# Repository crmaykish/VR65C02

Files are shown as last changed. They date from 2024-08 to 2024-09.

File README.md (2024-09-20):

# VR65C02
A 6502 computer system with an ATmega4809 simulating all of the memory and I/O. Two ICs are enough to run native 6502 code on the real silicon. All of the 6502's interactions with the outside world go through the microcontroller.

It's like the 6502 is wearing the ATmega as a VR headset! (AVR headset?)

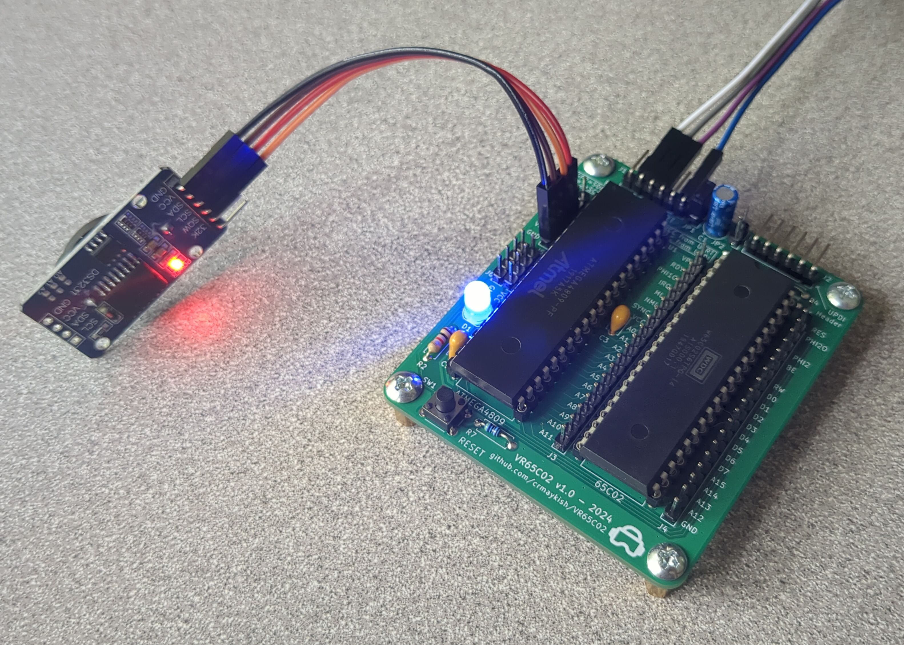
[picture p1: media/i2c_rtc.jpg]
Prototype


## Background

### TL;DR

- Real 6502 code running on a real 6502
- ATmega4809 microcontroller emulates everything else
- 6502 is programmed by uploading an Arduino sketch
- 5KB of emulated RAM, up to 32KB emulated ROM
- Memory-mapped UART, GPIO, and I2C peripherals for the 6502
- Eye-watering clock speed of ~250 kHz!

### Why?

Why not? This project started as a weekend experiment to see if I could run a 6502 CPU without having to use a real ROM chip. That quickly turned into "Can I run 6502 code on a real CPU without any real memory or peripherals attached. The answer is yes.

This computer is not fast. It's not practical, but it is kind of fun.

### Why not a Raspberry Pi Pico or FPGA?

Those would both likely be better choices, but to be totally honest, the availability of the ATmega4809 in a 40 pin DIP package is what sold me. I like the aesthetic of two DIP ICs. That's really it.

## Features

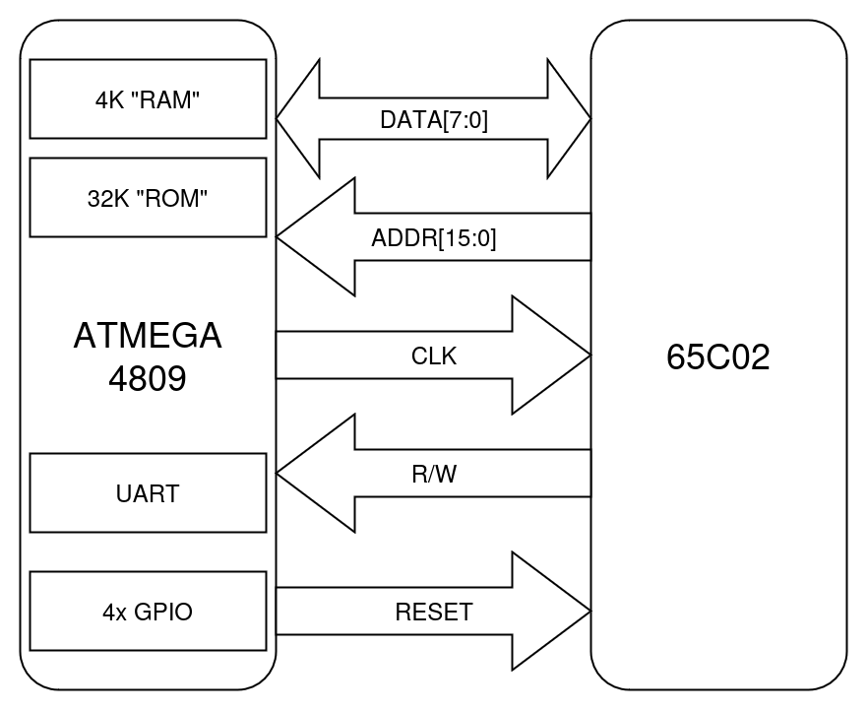
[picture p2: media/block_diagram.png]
VR65C02 Block Diagram


### Memory Emulation

VR65C02 is a fully functional computer system. The ATmega microcontroller provides emulated RAM and ROM as well as a passthrough UART and four GPIO pins that the 6502 can access.

The microcontroller controls the RESET and CLOCK lines of the CPU, so all memory access is handled synchronously by the Arduino code. For each bus cycle, the microcontroller reads the address bus and R/W pin from the CPU. If the CPU is reading a memory address, the microcontroller will decode the address into a memory value or an I/O operation and write the appropriate value out to the data bus. On a write cycle, the microcontroller reads the data bus value into its simulated RAM or updates the appropriate I/O system. The microcontroller implements address decoding in code in a similar way to a traditional system using logic gates or PLDs.

Both RAM and ROM are backed by large byte arrays in the microcontroller's memory, the RAM using onboard SRAM and the ROM using onboard Flash.

### I/O Emulation

The UART is a memory-mapped I/O device from the perspective of the 6502, similar to a 6551 ACIA. The CPU can read and write bytes and the microcontroller passes them through to one of its native serial ports.

Similarly, there are four GPIO pins accessible as a memory-mapped register to the 6502.

These GPIO ports have two alternate functions. If SOFT_RESET is defined in [memory_map.h](src/6502_vr_goggles/memory_map.h), then GPIO pin 0 will function as a reset pin for the 6502. It does not reset the Arduino, but it triggers the Arduino to reset the 6502. If soft reset is enabled, pin 0 cannot be used as a normal GPIO pin.

I2C devices can also be attached to the GPIO pins. GPIO 2 and 3 double as SDA and SCL respectively. The Arduino provides low level access to the I2C bus through a few memory-mapped registers. The 6502 can enable/disable the I2C bus, set the active peripheral address, and read/write data through these registers.

See [memory_map.h](src/6502_vr_goggles/memory_map.h) for more details.

It should also be possible to implement SPI passthrough in a similar fashion, but I2C is really a better fit for this system, especially considering its slow clock speed and lack of I/O lines. With I2C, a ton of peripherals can be daisy-chained and there is still room for 1 or 2 GPIO pins. I've tested reading a real-time clock module over I2C from the 6502 code (see the `time` command in [monitor.c](src/monitor.c)).

### Memory Map

The memory map of the 6502 is as follows:
1. 5KB "RAM" at 0x0000
2. I/O regisers at 0x7F00
3. 8KB "ROM" at 0xE000

The ATmega4809 has enough flash memory to support up to 32KB of ROM if necessary, but the total onboard SRAM is only 6KB and some is set aside for the Arduino code.

## Software

The core of VR65C02 is the Arduino sketch running on the ATmega4809. As described above, this program simulates the entire bus cycle of the physical 6502 CPU and all of the memory and I/O interactions.

Real 6502 machine code is running on the CPU. This can be assembly or C code compiled with cc65. Since there is no physical ROM or RAM, the code has to live somewhere. My approach is to use the large amount of onboard Flash memory of the ATmega to store this. The main trick of VR65C02 is taking this compiled binary and getting it into the microcontroller Flash as part of the Arduino sketch upload.

### Setup

To build and deploy code to the VR65C02, you'll need to setup the following:
1. Install Arduino to `/opt/local`
2. Install MegaCoreX Arduino package
3. Install cc65 or some other 6502 compiler/assembler
4. Install make (`build-essential` on Debian/Ubuntu)
5. Install Python 3.x

Note: you may need to update the build.sh script if you're on a different platform. Windows will probably require a different approach.

### Building

The build process is done in a single script, [build.sh](src/build.sh). The process looks like this:
1. Compile 6502 C code into a binary ROM file.
2. Run a Python script to convert this binary file into a C header file with a large const array of bytes.
3. Compile the Arduino sketch with this generated header file.
4. Upload Arduino sketch to microcontroller with new 6502 code.

### Programming the ATmega (and by extension the 6502)

Programming the ATmega4809 is done via UPDI. UPDI is a one-wire programming interface that can be implemented over a simple serial port. On VR65C02, the wiring is already done on the board, so a standard FTDI-style USB-UART can be plugged into the onboard UPDI header. In the Arduino IDE, the SerialUPDI programmer included in MegaCoreX at 230400 baud will work just fine. Make sure to set the serial port to the UPDI USB device and not the one plugged into the UART port.

Note: the board and programmer selection is already done in the [build.sh](src/build.sh) script using the `arduino-cli` command.

It's possible to use a single FTDI device and switch between the headers on board for programming versus serial monitoring, but having two different serial ports is a lot more convenient.

## Limitations

All of the limitations of this system come down to hitting the limits of the ATmega4809 itself in one way or another.

### Clock Speed

The main drawback is obviously clock speed. Simulating the whole bus cycle and all of the potential memory and I/O operations of the 6502 on a 20 MHz 8-bit microcontroller is not exactly quick. Measuring the PHI2 output on the CPU with an oscilloscope shows that the effective clock speed is about 257 kHz. Even at this speed, VR65C02 is surprisingly usable for simple GPIO tasks or interacting over the serial port, but it's about 4x slower than a Commodore 64 or Apple II.

Because not all the emulated peripherals respond at the same speed, the effective clock speed is actually somewhat variable depending on the I/O demands of the 6502 code. This doesn't fluctuate too dramatically, but heavy I/O, e.g. polling the serial port, will run at around 257 kHz, whereas no I/O at all will get the clock up to about 270 kHz.

### Not Enough Pins

Besides the slow speed, the other main limitations is the lack of available pins on the ATmega. All 31 available IO pins are being used to connect to the 6502 bus and control signals. Two of the pins are used for the serial port and four are set up as GPIO. The GPIO pins could be used for other things, but there's not a huge number to spare.

In theory, these GPIO pins could be repurposed as chip-select signals to attach some real I/O devices to the system. It wouldn't be a stretch to attach a real RAM chip and have the microcontroller copy the program code from Flash into that RAM. In that scenario, a real clock oscillator could be used and the Arduino would become a slow peripheral using the RDY pin to handle the higher clock rate.

The ATmega4809 is also available in a 48 pin QFP package with quite a few more I/O pins. This might be fun to explore, but it would definitely detract from the DIP aesthetic and make VR65C02 harder to build.

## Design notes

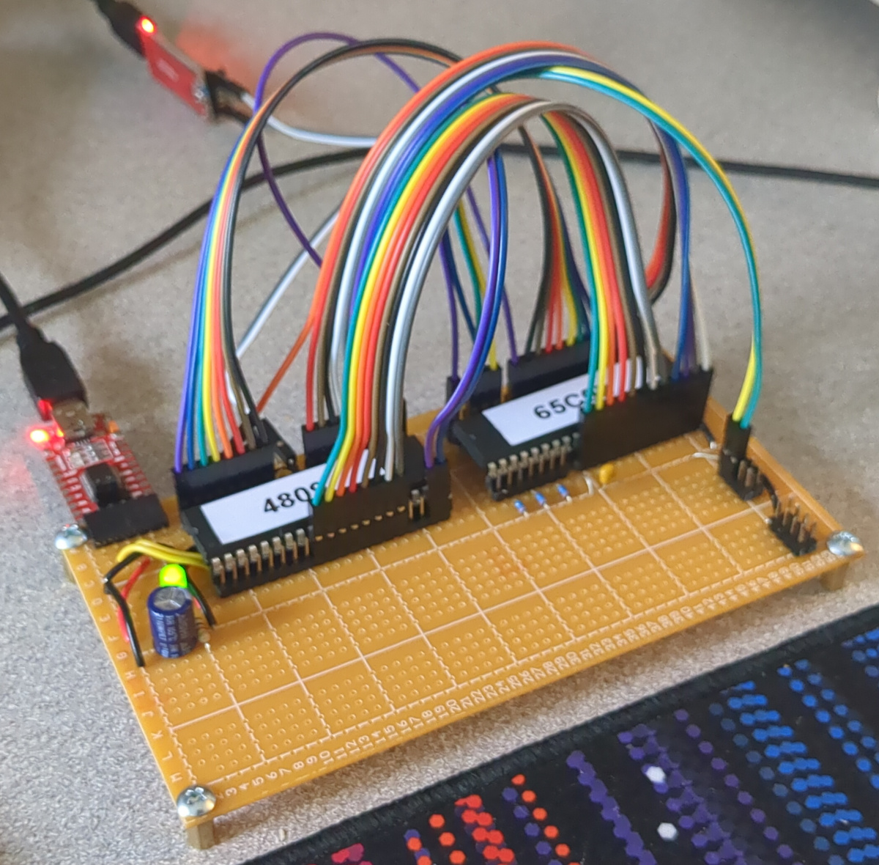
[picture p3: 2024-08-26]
media/prototype.jpg

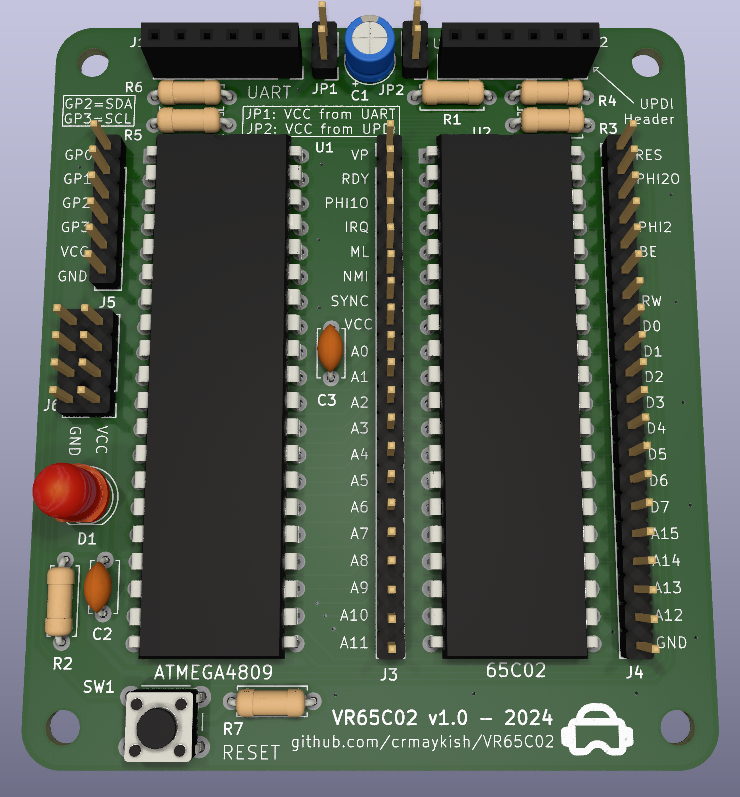
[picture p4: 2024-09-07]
media/render1.png

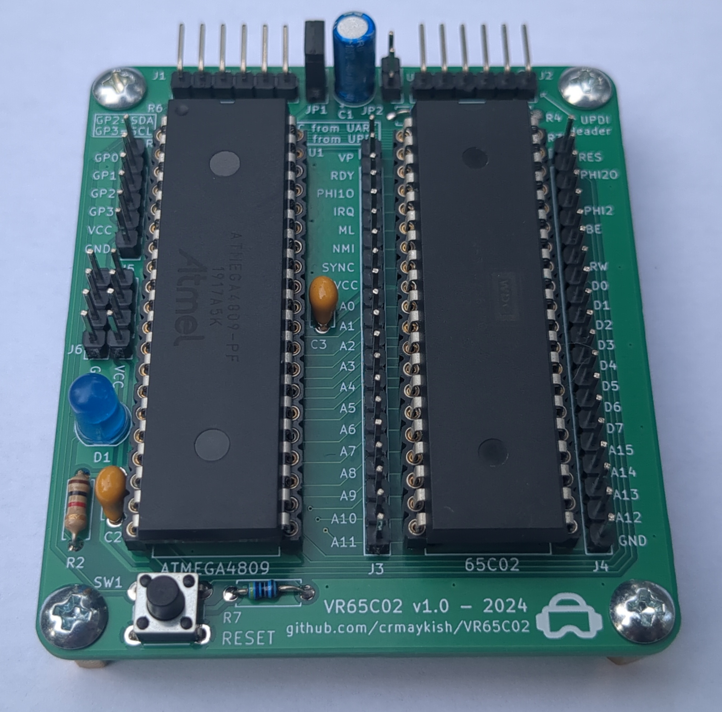
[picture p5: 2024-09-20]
media/pcb_v1.jpg

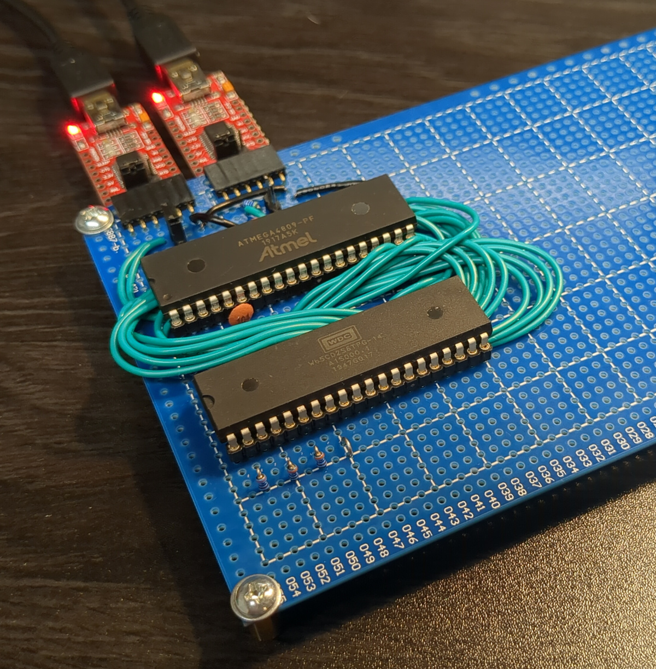
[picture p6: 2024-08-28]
media/prototype2.jpg

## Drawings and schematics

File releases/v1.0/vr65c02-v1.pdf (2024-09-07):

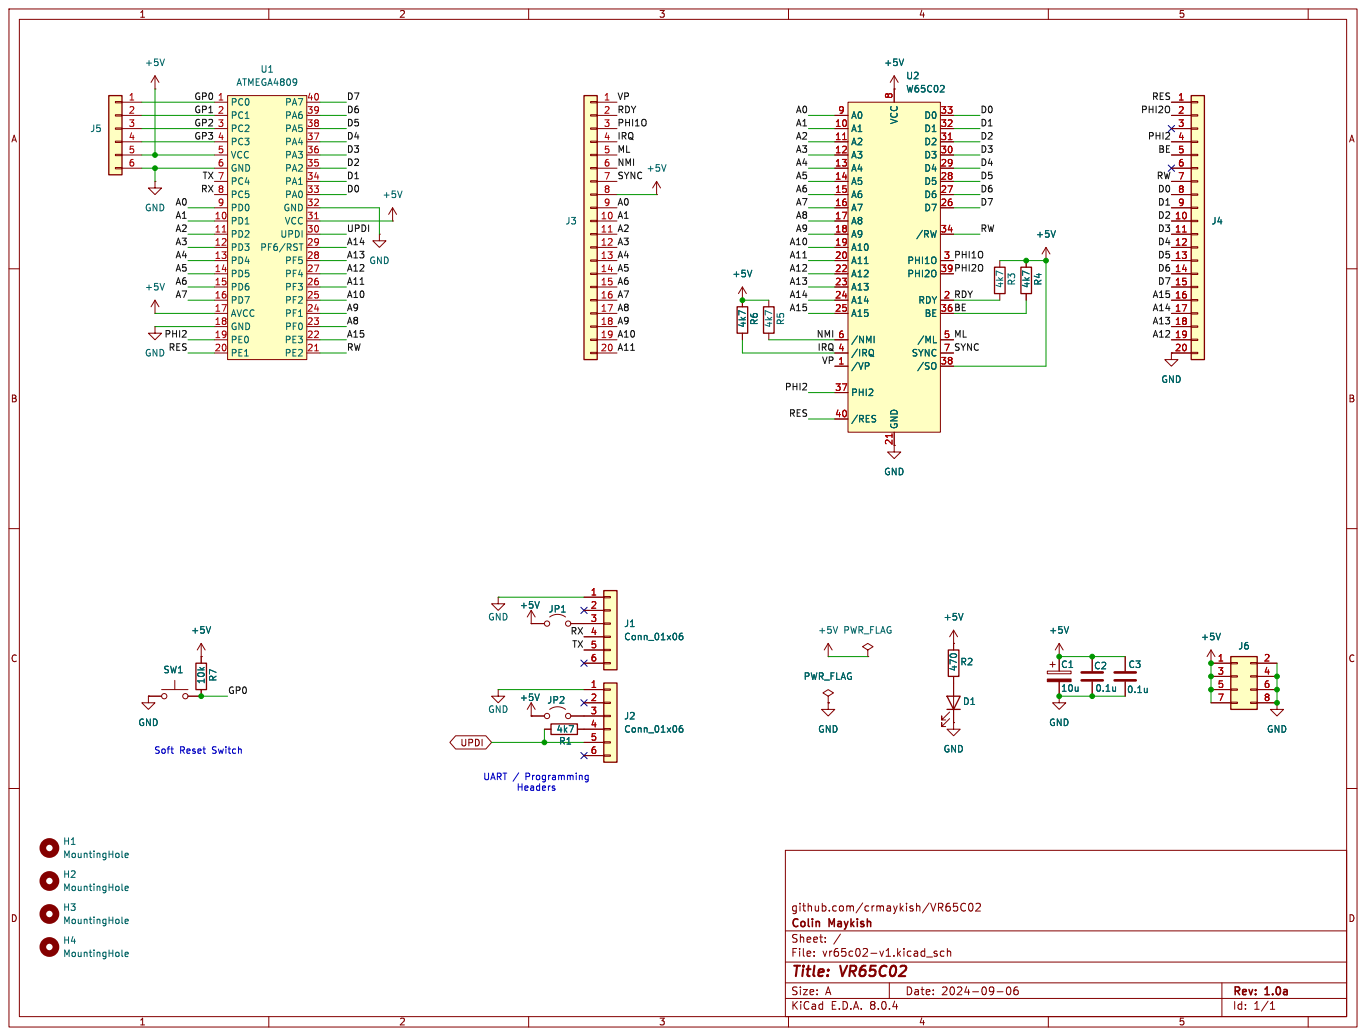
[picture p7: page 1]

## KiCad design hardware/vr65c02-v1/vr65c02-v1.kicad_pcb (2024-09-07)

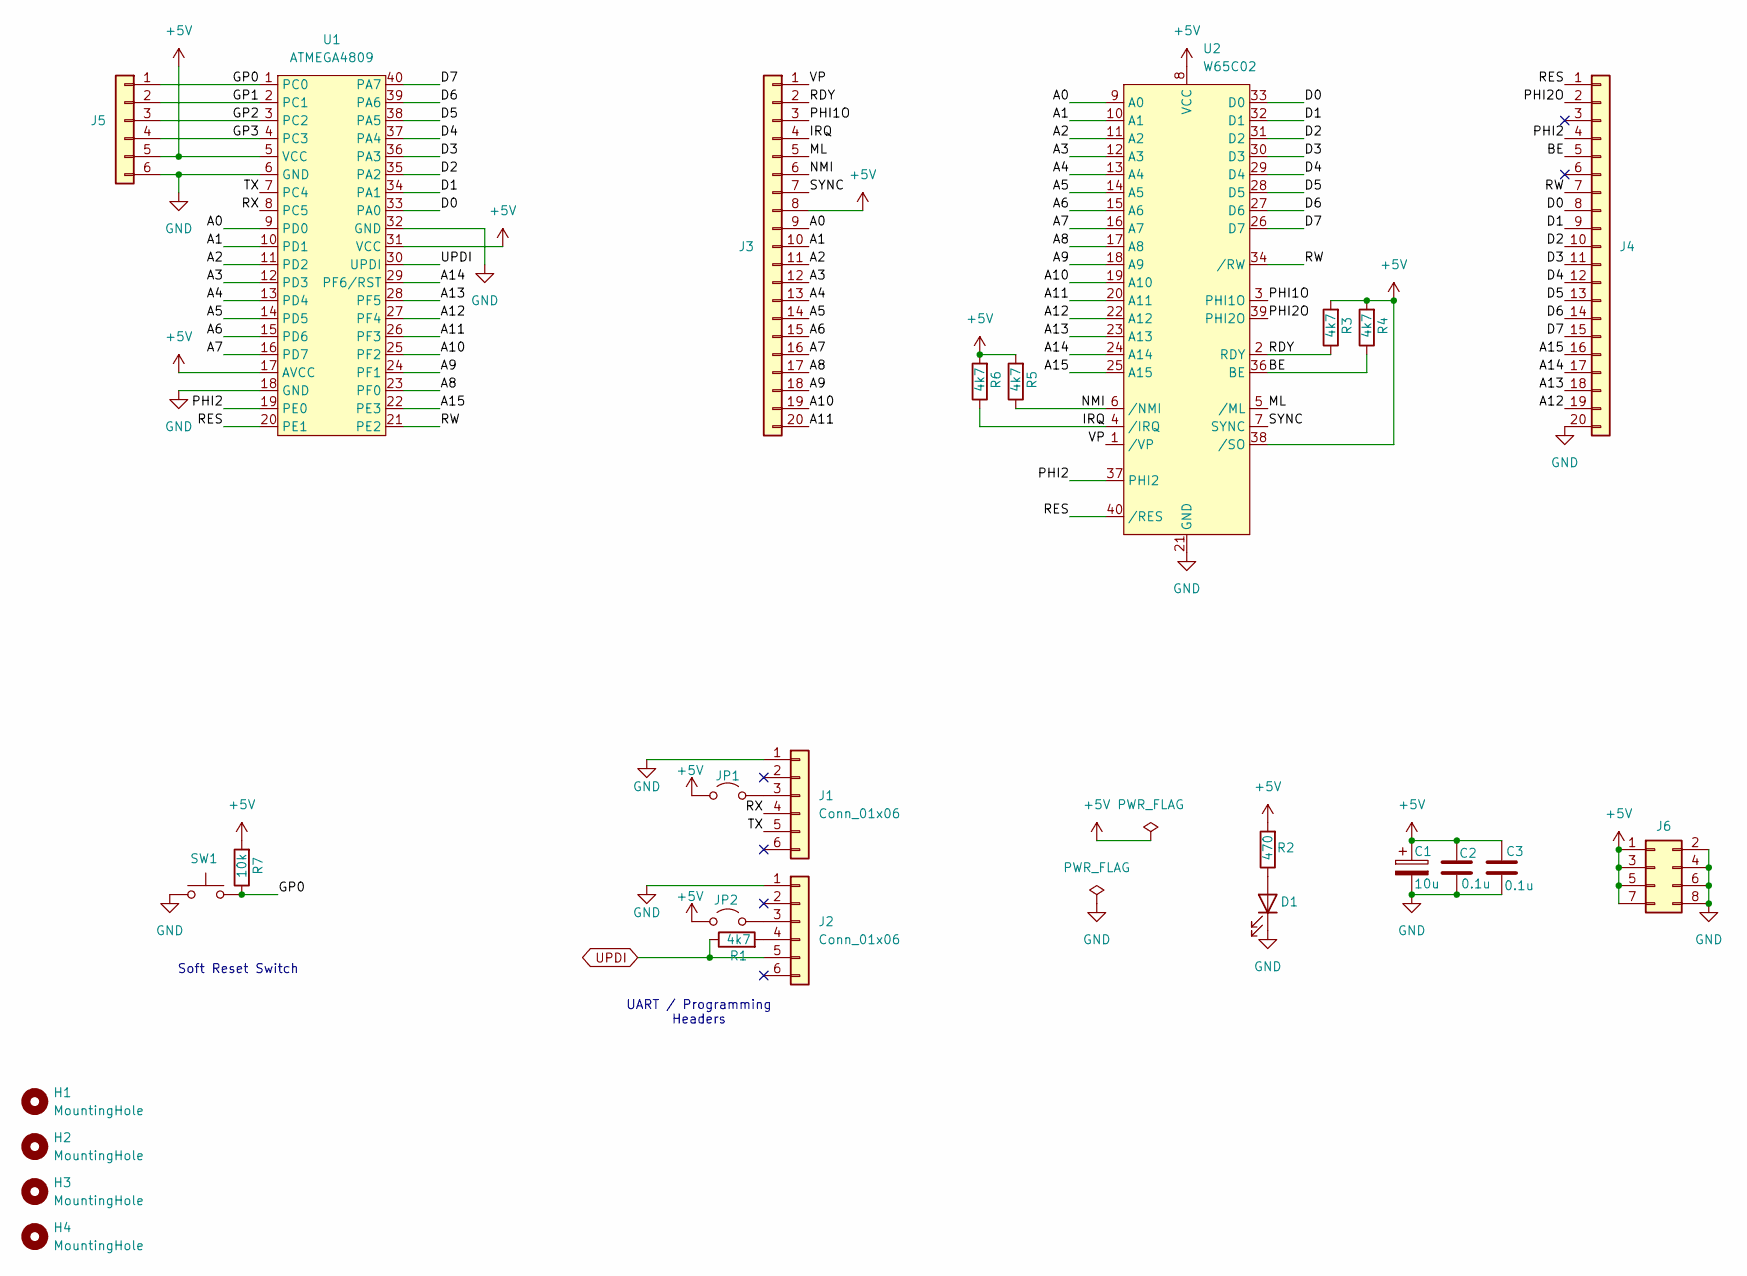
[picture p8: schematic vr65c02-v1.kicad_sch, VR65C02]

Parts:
C1: 10u; CP_Radial_D5.0mm_P2.50mm
C2, C3: 0.1u; C_Disc_D4.7mm_W2.5mm_P5.00mm
D1: LED; LED_D5.0mm
H1, H2, H3, H4: MountingHole; MountingHole_3.2mm_M3
J1, J2: Conn_01x06; PinSocket_1x06_P2.54mm_Vertical
J3, J4: Conn_01x20; PinHeader_1x20_P2.54mm_Vertical
J5: Conn_01x06; PinHeader_1x06_P2.54mm_Vertical
J6: Conn_02x04_Odd_Even; PinHeader_2x04_P2.54mm_Vertical
JP1, JP2: Jumper_2_Open; PinHeader_1x02_P2.54mm_Vertical
R1, R3, R4, R5, R6: 4k7; R_Axial_DIN0207_L6.3mm_D2.5mm_P7.62mm_Horizontal
R2: 470; R_Axial_DIN0207_L6.3mm_D2.5mm_P7.62mm_Horizontal
R7: 10k; R_Axial_DIN0207_L6.3mm_D2.5mm_P7.62mm_Horizontal
SW1: SW_Push; SW_PUSH_6mm_H5mm
U1: ATMEGA4809; DIP-40_W15.24mm
U2: W65C02; DIP-40_W15.24mm

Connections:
+5V: C1.1, C2.1, C3.1, J3.8, J5.5, J6.1, J6.3, J6.5, J6.7, JP1.1 (A), JP2.1 (A), R2.2, R3.2, R4.2, R5.2, R6.2, R7.2, U1.5 (VCC), U1.17 (AVCC), U1.31 (VCC), U2.8 (VCC), U2.38 (/SO)
/A0: J3.9, U1.9 (PD0), U2.9 (A0)
/A1: J3.10, U1.10 (PD1), U2.10 (A1)
/A2: J3.11, U1.11 (PD2), U2.11 (A2)
/A3: J3.12, U1.12 (PD3), U2.12 (A3)
/A4: J3.13, U1.13 (PD4), U2.13 (A4)
/A5: J3.14, U1.14 (PD5), U2.14 (A5)
/A6: J3.15, U1.15 (PD6), U2.15 (A6)
/A7: J3.16, U1.16 (PD7), U2.16 (A7)
/A8: J3.17, U1.23 (PF0), U2.17 (A8)
/A9: J3.18, U1.24 (PF1), U2.18 (A9)
/A10: J3.19, U1.25 (PF2), U2.19 (A10)
/A11: J3.20, U1.26 (PF3), U2.20 (A11)
/A12: J4.19, U1.27 (PF4), U2.22 (A12)
/A13: J4.18, U1.28 (PF5), U2.23 (A13)
/A14: J4.17, U1.29 (PF6/RST), U2.24 (A14)
/A15: J4.16, U1.22 (PE3), U2.25 (A15)
/BE: J4.5, R4.1, U2.36 (BE)
/D0: J4.8, U1.33 (PA0), U2.33 (D0)
/D1: J4.9, U1.34 (PA1), U2.32 (D1)
/D2: J4.10, U1.35 (PA2), U2.31 (D2)
/D3: J4.11, U1.36 (PA3), U2.30 (D3)
/D4: J4.12, U1.37 (PA4), U2.29 (D4)
/D5: J4.13, U1.38 (PA5), U2.28 (D5)
/D6: J4.14, U1.39 (PA6), U2.27 (D6)
/D7: J4.15, U1.40 (PA7), U2.26 (D7)
/GP0: J5.1, R7.1, SW1.2, U1.1 (PC0)
/GP1: J5.2, U1.2 (PC1)
/GP2: J5.3, U1.3 (PC2)
/GP3: J5.4, U1.4 (PC3)
/IRQ: J3.4, R6.1, U2.4 (/IRQ)
/ML: J3.5, U2.5 (/ML)
/NMI: J3.6, R5.1, U2.6 (/NMI)
/PHI1O: J3.3, U2.3 (PHI1O)
/PHI2: J4.4, U1.19 (PE0), U2.37 (PHI2)
/PHI2O: J4.2, U2.39 (PHI2O)
/RDY: J3.2, R3.1, U2.2 (RDY)
/RES: J4.1, U1.20 (PE1), U2.40 (/RES)
/RW: J4.7, U1.21 (PE2), U2.34 (/RW)
/RX: J1.4, U1.8 (PC5)
/SYNC: J3.7, U2.7 (SYNC)
/TX: J1.5, U1.7 (PC4)
/VP: J3.1, U2.1 (/VP)
GND: C1.2, C2.2, C3.2, D1.1 (K), J1.1, J2.1, J4.20, J5.6, J6.2, J6.4, J6.6, J6.8, SW1.1, U1.6 (GND), U1.18 (GND), U1.32 (GND), U2.21 (GND)
unnamed: D1.2 (A), R2.1
unnamed: J1.3, JP1.2 (B)
unnamed: J2.3, JP2.2 (B)
unnamed: J2.4, R1.2
UPDI: J2.5, R1.1, U1.30 (UPDI)

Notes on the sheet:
Soft Reset Switch
UART / Programming Headers

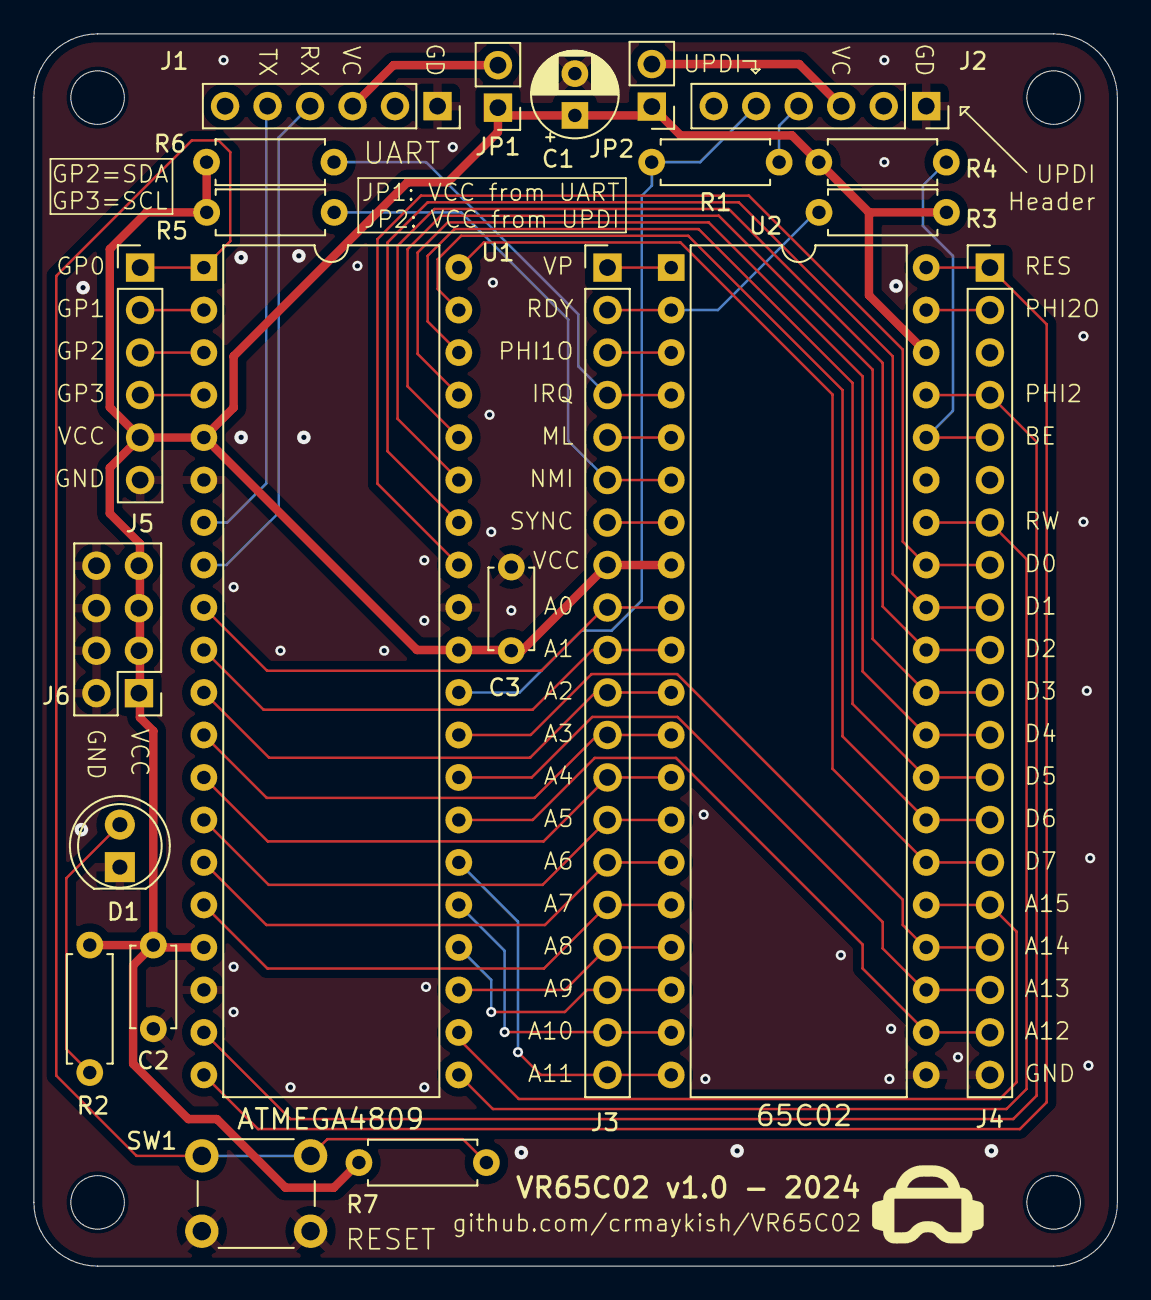
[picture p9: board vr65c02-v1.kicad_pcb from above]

Board: 2 copper layers, 64.8 x 73.7 mm, 26 parts (0 on the bottom side), 49 nets.

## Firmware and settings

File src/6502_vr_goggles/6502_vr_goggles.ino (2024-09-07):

#include "6502_rom_bin.h"
#include "memory_map.h"
#include <Wire.h>

// MCU pins
#ifdef SOFT_RESET
#define SOFT_RES_SW PIN_PC0
#endif

// CPU control pins
#define RESB PIN_PE1
#define CLK PIN_PE0
#define RWB PIN_PE2

// CPU buses
#define DATA_BUS VPORTA
#define ADDR_LOW VPORTD
#define ADDR_HIGH VPORTF
#define A15 PIN_PE3
#define VIA_PORT PORTC

// Byte array acts as system RAM for the 6502
uint8_t RAM[RAM_SIZE] = {0};

// NOTE: ROM content is defined in the generated header file 6502_rom_bin.h

uint16_t addr = 0;
uint8_t data = 0;
bool rw = 0;

uint8_t i2c_dev = 0;

void reset_6502() {
    digitalWriteFast(RESB, LOW);

    // Toggle the clock a few times with the reset pin LOW
    for (int i = 0; i < 50; i++) {
        digitalWriteFast(CLK, LOW);
        delay(2);
        digitalWriteFast(CLK, HIGH);
        delay(2);
    }

    // Take 6502 out of reset
    digitalWriteFast(RESB, HIGH);
}

void setup() {
    // Setup buses as input
    ADDR_LOW.DIR = 0;
    ADDR_HIGH.DIR = 0;
    DATA_BUS.DIR = 0;
    pinMode(A15, INPUT);

    // Setup CPU control pins
    pinMode(RWB, INPUT);
    pinMode(RESB, OUTPUT);
    pinMode(CLK, OUTPUT);
    digitalWriteFast(RESB, LOW);
    digitalWriteFast(CLK, HIGH);

    // Setup "VIA" pins
    VIA_PORT.DIRCLR = 0b00001111;

#ifdef SOFT_RESET
    pinMode(SOFT_RES_SW, INPUT);
#endif

    Serial1.swap(1);
    Serial1.begin(115200);

    reset_6502();
}

void loop() {
#ifdef SOFT_RESET
    if (!digitalReadFast(SOFT_RES_SW)) {
        reset_6502();
    }
#endif

    // PHI goes LOW
    digitalWriteFast(CLK, LOW);

    // Delay slightly, giving the 6502 time to react to the falling clock edge
    // before reading the buses
    asm("nop");
    asm("nop");

    rw = digitalReadFast(RWB);
    addr = (digitalReadFast(A15) << 15) | (ADDR_HIGH.IN << 8) | ADDR_LOW.IN;

    if (rw) {
        // 6502 is reading from memory
        DATA_BUS.DIR = 0xFF;

        if (addr >= ROM_START) {
            // Read from "ROM"
            DATA_BUS.OUT = ROM[addr % ROM_SIZE];
        } else if (addr < RAM_SIZE) {
            // Read from "RAM"
            DATA_BUS.OUT = RAM[addr];
        } else if (addr == UART_RX_RDY) {
            // Read from UART RX ready register
            DATA_BUS.OUT = (Serial1.available() > 0) ? 0x01 : 0x00;
        } else if (addr == UART_RX) {
            // Read from serial port
            DATA_BUS.OUT = Serial1.read();
        } else if (addr == VIA) {
            // Read from VIA GPIO
            DATA_BUS.OUT = VIA_PORT.IN & 0xF;
        } else if (addr == VIA_DIR) {
            // Read from VIA direction register
            DATA_BUS.OUT = VIA_PORT.DIR & 0xF;
        } else if (addr == I2C_DATA) {
            Wire.requestFrom(i2c_dev, 1);
            if (Wire.available()) {
                DATA_BUS.OUT = Wire.read();
            } else {
                DATA_BUS.OUT = 0;
            }
        } else if (addr == I2C_ADDR) {
            DATA_BUS.OUT = i2c_dev;
        }
    } else {
        // 6502 is writing to memory
        DATA_BUS.DIR = 0x00;
    }

    // PHI goes HIGH
    digitalWriteFast(CLK, HIGH);
    // NOTE: The 6502 does not seem to require a delay on the rising edge
    // of the clock like it does on the falling edge

    if (!rw) {
        // Read the data bus
        data = DATA_BUS.IN;

        if (addr < RAM_SIZE) {
            // Write data bus to "RAM"
            RAM[addr] = data;
        } else if (addr == UART_TX) {
            // Write data bus to UART
            Serial1.write(data);
        } else if (addr == VIA) {
            // Write data bus to "VIA"
            VIA_PORT.OUT = (data & 0xF);
        } else if (addr == VIA_DIR) {
            // Write to VIA GPIO direction register
#ifdef SOFT_RESET
            // If soft reset switch is active, ignore the lowest bit
            VIA_PORT.DIRCLR = 0b00001110;
            VIA_PORT.DIRSET = data & 0b00001110;
#else
            // Otherwise, use the lowest four bits of the port as GPIO
            VIA_PORT.DIRCLR = 0xF;
            VIA_PORT.DIRSET = data & 0xF;
#endif
        } else if (addr == I2C_CTRL) {
            // Turn on or off the I2C function of the GPIO pins
            if (data & 0b01) {
                Wire.swap(1);
                Wire.begin();
            } else {
                Wire.end();
            }
        } else if (addr == I2C_ADDR) {
            // Set I2C device address
            i2c_dev = data;
        } else if (addr == I2C_DATA) {
            // Write a byte to active I2C device
            Wire.beginTransmission(i2c_dev);
            Wire.write(data);
            Wire.endTransmission();
        }
    }
}

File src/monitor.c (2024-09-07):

#include "vr65c02.h"
#include <6502.h>
#include <peekpoke.h>
#include <stdbool.h>
#include <stdint.h>
#include <stdio.h>
#include <stdlib.h>
#include <string.h>

#define PROMPT ">"

#define INPUT_BUFFER_SIZE 32
#define COMMAND_MAX_LENGTH 6
#define MEMDUMP_BYTES 128

typedef struct {
    char name[6];
    char param1[6];
    char param2[6];
    char desc[48];
    void (*handler)();
} command_t;

void header();
void prompt();
void free_ram();
uint8_t readline(char *buffer);
void memdump(uint16_t address, uint8_t bytes);

void handler_help();
void handler_info();
void handler_peek();
void handler_poke();
void handler_dump();
void handler_demo();
void handler_time();
void command_not_found(char *command_name);

// CPU type names
static const char *cpu_names[] = {"6502", "65C02",  "65816",
                                  "4510", "65SC02", "65CE02"};

static const command_t commands[] = {
    {"help", "", "", "Show this message", handler_help},
    {"info", "", "", "Get system info", handler_info},
    {"peek", "addr", "", "Peek at a memory address", handler_peek},
    {"poke", "addr", "val", "Poke a value into memory", handler_poke},
    {"dump", "addr", "", "Dump memory in hex and ASCII", handler_dump},
    {"demo", "", "", "Run a hardware demo", handler_demo},
    {"time", "", "", "Display the current time", handler_time},
};

static const uint8_t COMMAND_COUNT = sizeof(commands) / sizeof(command_t);

int main() {
    uint8_t i;
    char buffer[INPUT_BUFFER_SIZE];
    char *command;
    bool command_handled;

    header();

    while (true) {
        command_handled = false;

        // Present the command prompt and wait for input
        prompt();
        readline(buffer);
        printf("\r\n");

        command = strtok(buffer, " ");

        // Look for the command name in the command list
        for (i = 0; i < COMMAND_COUNT; i++) {
            if (strncmp(command, commands[i].name, COMMAND_MAX_LENGTH) == 0) {
                // Found the command, handle it
                commands[i].handler();
                command_handled = true;
                break;
            }
        }

        if (!command_handled) {
            command_not_found(command);
        }

        printf("\r\n");
    }

    return 0;
}

void header() { printf("\r\n*** VR65C02 Monitor ***\r\n"); }

void prompt() { printf("%s ", PROMPT); }

void free_ram() { printf("%d bytes free", _heapmemavail()); }

void handler_help() {
    uint8_t i = 0;

    printf("Available commands:\r\n");

    for (i = 0; i < COMMAND_COUNT; i++) {
        printf(commands[i].name);

        if (commands[i].param1[0] != '\0') {
            printf(" <");
            printf(commands[i].param1);
            printf(">");
        }
        if (commands[i].param2[0] != '\0') {
            printf(" <");
            printf(commands[i].param2);
            printf(">");
        }

        printf(" : ");

        printf(commands[i].desc);

        if (i != COMMAND_COUNT - 1) {
            printf("\r\n");
        }
    }
}

void handler_info() {
    printf("CPU: ");
    printf(cpu_names[getcpu()]);
    printf("\r\nRAM: ");
    free_ram();
}

void handler_peek() {
    char *param1 = strtok(NULL, " ");
    uint16_t addr = strtol(param1, 0, 16);

    printf("%02X", PEEK(addr));
}

void handler_poke() {
    char *param1 = strtok(NULL, " ");
    char *param2 = strtok(NULL, " ");

    uint16_t addr = strtol(param1, 0, 16);
    uint8_t val = strtol(param2, 0, 16);

    POKE(addr, val);
    printf("OK");
}

void handler_dump() {
    char *param1 = strtok(NULL, " ");
    uint16_t addr = strtol(param1, 0, 16);

    memdump(addr, MEMDUMP_BYTES);
}

void handler_demo() {
    char rx = 0;
    unsigned char io = 0;

    // Set all GPIO pins to output
    POKE(VIA_DIR, 0xF);

    while (1) {
        // Watch for escape key press
        if (PEEK(UART_RX_RDY) == 1) {
            rx = PEEK(UART_RX);

            if (rx == 0x1B) {
                printf("Stopping demo.");
                POKE(VIA_DIR, 0);
                return;
            }
        }

        printf("GPIO: %01X\r\n", io);
        POKE(VIA, io);
        io++;
    }
}

uint8_t bcd2bin(uint8_t val) { return val - 6 * (val >> 4); }

void handler_time() {
    uint8_t b[7] = {0};
    int i = 0;
    uint8_t ack = 0;

    printf("Reading time...\r\n");

    // Init I2C
    POKE(I2C_CTRL, 1);

    // Set I2C device address
    POKE(I2C_ADDR, 0x68); // RTC address is 0x68

    // Send "now" command
    POKE(I2C_DATA, 0);

    // Read ack
    ack = PEEK(I2C_DATA);

    // Read 7 bytes of datetime from the RTC
    b[0] = bcd2bin(PEEK(I2C_DATA));
    b[1] = bcd2bin(PEEK(I2C_DATA));
    b[2] = bcd2bin(PEEK(I2C_DATA));
    b[3] = bcd2bin(PEEK(I2C_DATA));
    b[4] = bcd2bin(PEEK(I2C_DATA));
    b[5] = bcd2bin(PEEK(I2C_DATA) & 0x7F);
    b[6] = bcd2bin(PEEK(I2C_DATA));

    printf("%04d-%02d-%02d %02d:%02d:%02d\r\n", b[6] + 2000, b[5], b[4], b[2],
           b[1], b[0]);
}

void print_string_bin(char *str, uint8_t max) {
    uint8_t i = 0;

    while (i < max) {
        if (str[i] >= 32 && str[i] < 127) {
            serial_putc(str[i]);
        } else {
            serial_putc('.');
        }

        i++;
    }
}

void memdump(uint16_t address, uint8_t bytes) {
    uint16_t i = 0;
    uint8_t b = 0;

    printf("%04X  ", address);

    while (i < bytes) {
        b = PEEK(address + i);
        printf("%02X ", b);

        i++;

        if (i % 16 == 0 && i < bytes) {
            printf(" |");
            print_string_bin((char *)(address + i - 16), 16);

            printf("|\r\n%04X  ", address + i);
        } else if (i % 8 == 0) {
            serial_putc(' ');
        }
    }

    serial_putc('|');
    print_string_bin((char *)(address + i - 16), 16);
    serial_putc('|');
}

void command_not_found(char *command_name) {
    printf("Command not found: %s", command_name);
}

uint8_t readline(char *buffer) {
    uint8_t count = 0;
    uint8_t in = serial_getc();

    while (in != '\n' && in != '\r') {
        // Character is printable ASCII
        if (in >= 0x20 && in < 0x7F) {
            serial_putc(in);

            buffer[count] = in;
            count++;
        }

        in = serial_getc();
    }

    buffer[count] = 0;

    return count;
}

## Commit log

2024-08-25 Copying 6502 binary to AVR flash memory as part of Arduino upload
2024-08-25 65C02 is running C code with stdlib support
    [mem.cfg]
2024-08-26 Document the prototype
2024-08-26 Move code into src folder
    [mem.cfg]
2024-08-26 Stubbed out schematic
    [vr65c02-v1.kicad_pcb, vr65c02-v1.kicad_sch]
2024-08-26 Add uart_getc function
2024-08-27 Photo of soldered prototype
2024-08-27 Switch to alternate UART pins
2024-08-27 Memory mapped now shared between Arduino and 6502 code
    [mem.cfg]
2024-08-28 Ported simple ROM monitor
    [mem.cfg]
2024-09-05 PCB v1 routed
    [vr65c02-v1.kicad_pcb, vr65c02-v1.kicad_sch]
2024-09-05 Add PCB render to README
2024-09-06 Basic soft reset button option
    [vr65c02-v1.kicad_pcb, vr65c02-v1.kicad_sch]
2024-09-07 Implement I2C passthrough to 6502
2024-09-07 PCB release v1.0a
    [vr65c02-v1.kicad_pcb, vr65c02-v1.kicad_sch]
2024-09-07 Render of PCB v1.0
2024-09-20 Add PCB images
